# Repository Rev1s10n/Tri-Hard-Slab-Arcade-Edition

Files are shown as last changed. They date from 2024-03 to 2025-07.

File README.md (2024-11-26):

# Tri-Hard Slab: Arcade Edition
## **English | [繁體中文](README_zh-TW.md)**
A follow up from my previous [build](https://github.com/Rev1s10n/Tri-Hard-slab-v2), powered by [GP2040-CE](https://gp2040-ce.info/) firmware (v.0.7.10) with custom 16 buttons layout.<br>
This time it's made with Cherry MX switches instead of Kailh Choc switches, and CNC aluminum case with acrylic top layer for art insert.

**I would suggest not build this yourself at this momemnt as there's some design flaws, which makes it really difficult to assemble**<br>
**A new case design might come in the future**

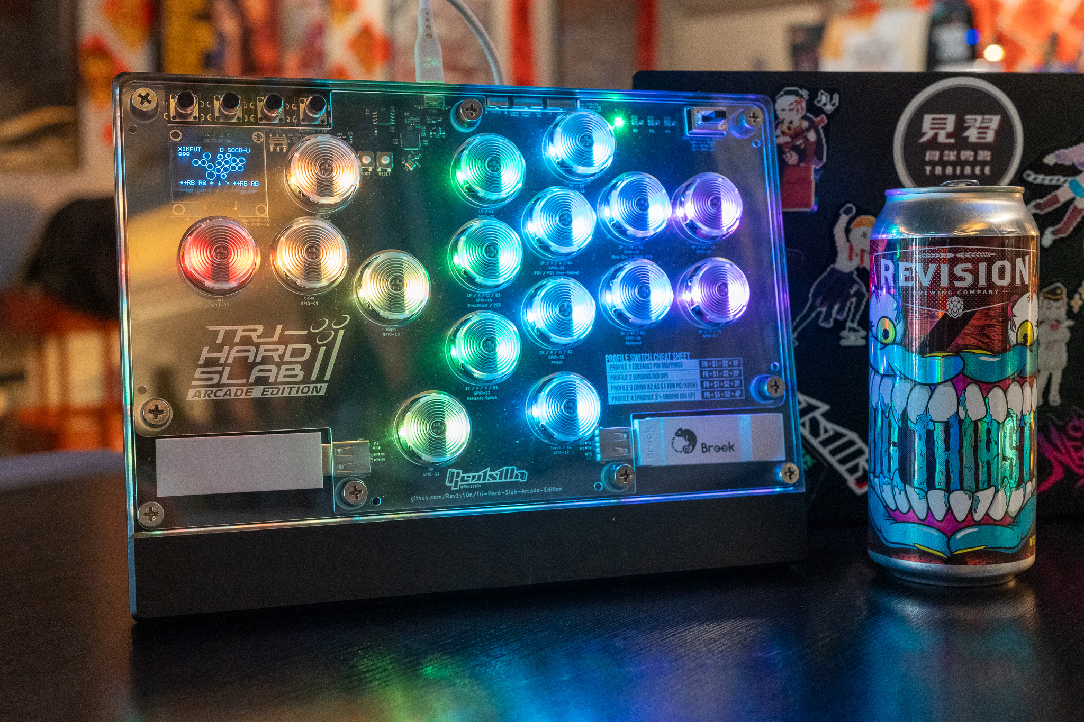
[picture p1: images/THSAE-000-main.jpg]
The beauty shot 2

## Key features and specs
- Dimensions: 270x200x24.1mm (including custom laser cut foampad)
- Weights: 1.3 kg
- Single CNC alumium case with laser cut acrylic sheet top panel and CNC polycarbonate mounting plate.
- Main key switches: any Cherry MX style switches, with hot swap sockets and Punk Workshop's key caps (25.5mm)
- Double RGB LED per key, and 4 RGB LEDs for player number indication.
- 2 USB Type-A connectors for passthrough devices, with slide switches to choose which one to activate.
- 1.3 inches OLED display.
- 3 slide switches on the top side for focus, SOCD and DP / LS / RS switch.
- Additional up button for general gaming purpose, and function key for quick profile swap.

Close up photos and feature explain:
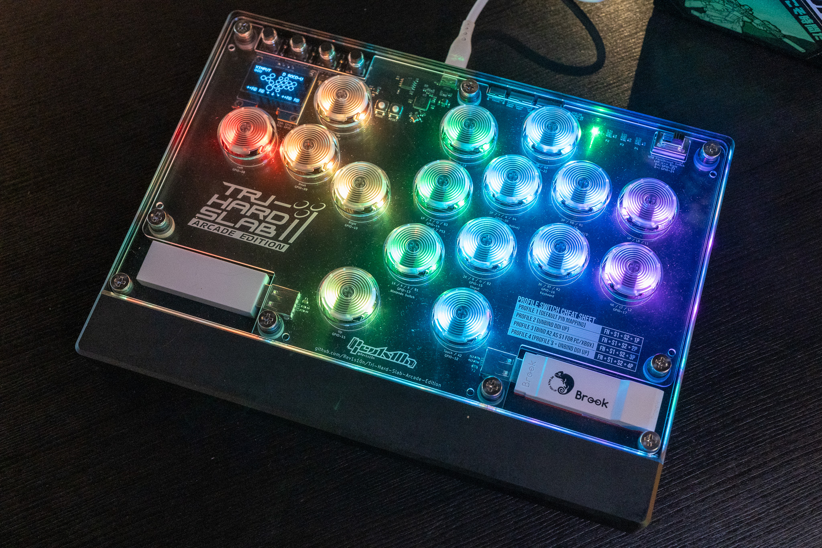
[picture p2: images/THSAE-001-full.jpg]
The core

_Fully redesigned circuit board with custom layout for my own comfort, passthrough device is now within the enclosure_
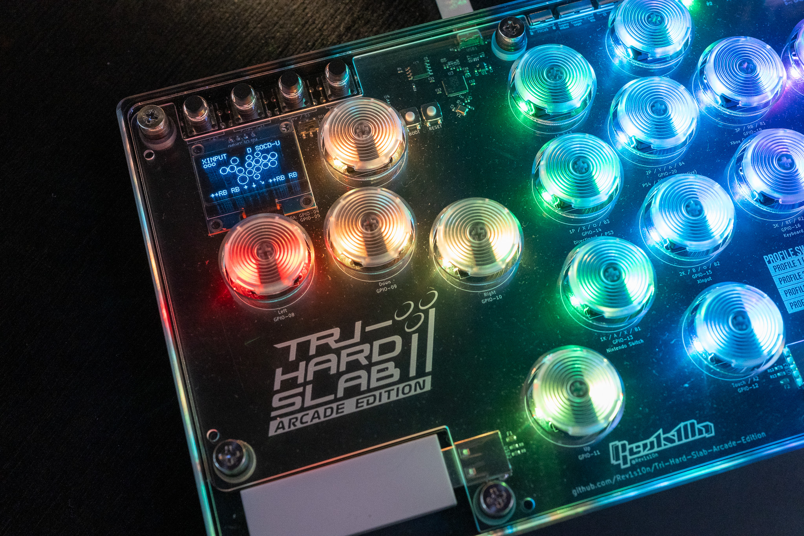
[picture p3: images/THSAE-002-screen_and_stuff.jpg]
Functions and display

_1 additional tactile switch for function key, and custom display layout_
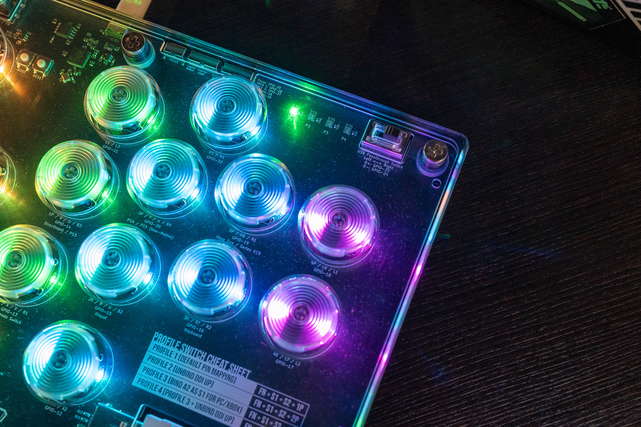
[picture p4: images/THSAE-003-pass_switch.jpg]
Passthrough switch

_Passthrough device can be selected with this slide switch_
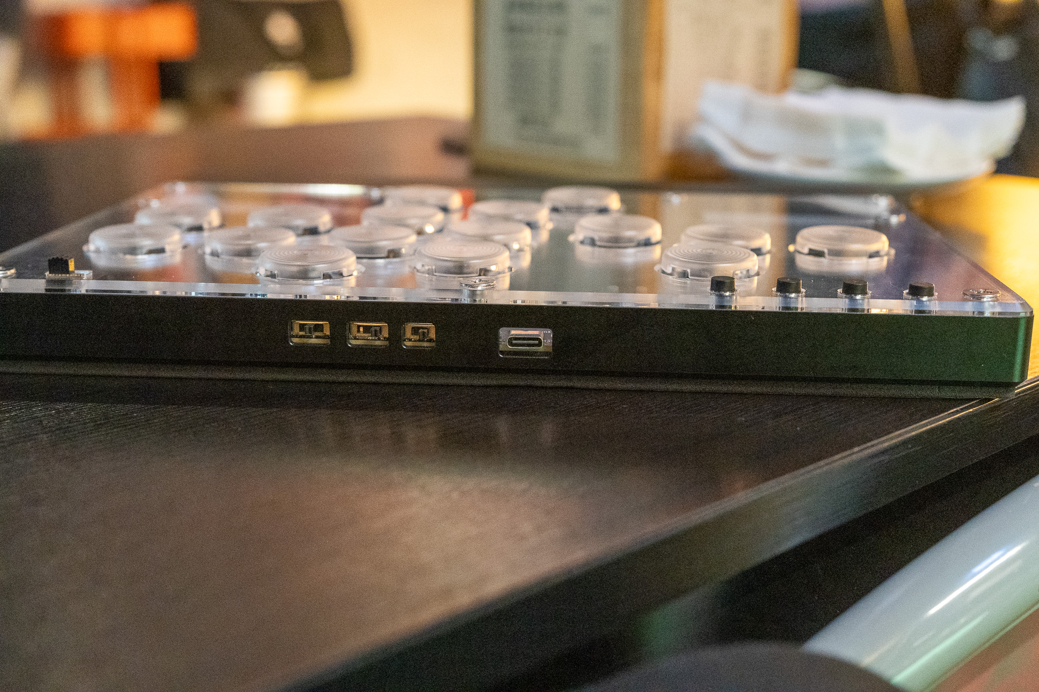
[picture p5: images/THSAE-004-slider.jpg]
Slide switches

_This time these switches is on the top side_

## Production files
Simply download all production files via Hardware files folder, and utilize services like JLCPCB (which is what I did in this case) to order the board.<br>
The board need standard PCBA for certain components. JLCPCB might told you there's some error (2 pins on 1 pad) but it's intended, and they'll make the board nevertheless.<br>
As for the case and acrylics / PC sheet, there's a step file for CNC aluminum case, 2 dxf files for laser cut acrylic, 1 dxf for CNC PC mounting plate.

## Source files
The Tri-Hard Slab AE is made with Autodesk Fusion 360 and KiCad 7.0.<br>
Everything is under Source files, include a rough Fusion 360 sketch which is the base of all laser-cut dxf files, step file and for KiCad to align things up.

## Assemble and settings
This is a bit tricky compare to original build.<br>
Here's some additional things you need to complete this build:
- Cherry MX switches, or any MX compatible switches, I use Cherry MX Black in this case.
- 16 Kailh MX hot swap socket (PG1511).
- 1.3 inches OLED display, make sure the pin order and set the slide switch accordingly.
- 9 M6 sex bolt / Chicago screws, with additional sink head screws
- Tons of hard and soft PVC washer (M6 sizes, 1mm thick) and NBR o-ring (6*2mm) for spacing.
- Custom laser cut EVA foams

There's a custom firmware with custom button layout for OLED display, and here's the GPIO pin mapping for reference:
|Keys|GPIO|
|-|-|
|Up|11|
|Down|9|
|Left|8|
|Right|10|
|B1/1K/A/Circle|13|
|B2/2K/B/Cross|15|
|B3/1P/X/Square|14|
|B4/2P/Y/Triangle|20|
|L1/4P/LB|18|
|R1/3P/RB|19|
|L2/4K/LT|17|
|R2/3K/RT|16|
|S1/Select/Back|1|
|S2/Start|3|
|L3/LS|21|
|R3/RS|22|
|A1/Home/Guide|2|
|A2/Touch|12|
|Function|0|
|Dual Direction Up|7|

Additional GPIO pin mapping and LED index for other features:
|Features|GPIO and index|
|-|-|
|RGB LED Data Pin|6|
|Player LEDs|starting from 32 to 35|
|Display SDA|4|
|Display SCL|5|
|Joystick Selection Slider Pin 1|26|
|Joystick Selection Slider Pin 2|25|
|SOCD Cleaning Mode Selection Slider Pin 1|28|
|SOCD Cleaning Mode Selection Slider Pin 2|27|
|PS Passthrough D+|23|
|PS Passthrough D-|24|
|Focus Mode Pin|29|

After load the setting file, there's 4 different profiles and there's shortcut combination to switch to any profile:
|Profile|Key combination|
|-|-|
|Profile 1 (Default pin mapping)|FN + S1 + S2 + 1P|
|Profile 2 (Unbind DDI Up)|FN + S1 + S2 + 2P|
|Profile 3 (Bind A2 as S1 for PC/Xbox)|FN + S1 + S2 + 3P|
|Profile 4 (Profile 3 + Unbind DDI Up)|FN + S1 + S2 + 4P|

## Custom artwork

You can download the PSD file and dxf drawing reference in Custom artwork template folder for top panel.<br>
Print it out and insert the artwork between 02 and 03 acrylic layers.

## Attribution
You're free to use this design as long as you credit to this page.<br>
[Licensed under CC BY 4.0](https://creativecommons.org/licenses/by/4.0/)

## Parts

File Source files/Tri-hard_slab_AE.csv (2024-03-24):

Id | Designator | Footprint | Quantity | Designation | Supplier and ref
1 | SW17,SW5,SW15,SW16,SW9,SW13,SW8,SW14,SW11,SW4,SW12,SW7,SW6,SW18,SW10 | SW_Hotswap_Kailh_Choc_V1V2 | 15 | SW_SPST
2 | SW21 | SS-13F24-G050 | 1 | ~
3 | SW3,SW2,SW1 | SW_PUSH-12mm | 3 | SW_Push
4 | SW19,SW20 | SS-12F23-G040 | 2 | ~
5 | UFB | Brook_Universal_Fighting_Board | 1 | brook_ufb
6 | R2,R1 | R_0805_2012Metric | 2 | 5.1k
7 | USB1 | USB_C_Receptacle_HRO_TYPE-C-31-M-12 | 1 | ~

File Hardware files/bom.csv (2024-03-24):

Designator | Footprint | Quantity | Value | LCSC Part #
C1, C10, C2, C8 | 0402 | 4 | 1u | C52923
C11, C12, C13, C14, C15, C16, C17, C18, C19, C20, C21, C22, C23, C24, C25, C26, C27, C28, C29, C30, C31, C32, C33, C34, C35, C36, C37, C38, C39, C40, C41, C42, C43, C44, C45, C46, C47, C48, C49, C5, C50, C51, C52, C53, C6, C7, C9 | 0402 | 47 | 100n | C1525
C3, C4 | 0402 | 2 | 30p | C161152
D1, D10, D11, D12, D13, D14, D15, D16, D17, D18, D19, D2, D20, D21, D22, D23, D24, D25, D26, D27, D28, D29, D3, D30, D31, D32, D33, D34, D35, D36, D4, D5, D6, D7, D8, D9 | SK6812-EC20 | 36 | SK6812 | C2909058
D37 | SOT-363_SC-70-6 | 1 | ~ | C15879
DS1 | 368030501246 | 1 | ~
F1, F2 | 0805 | 2 | Fuse | C116170
R1, R2 | 0402 | 2 | 5.1k | C25905
R10, R4 | 0402 | 2 | 10k | C25744
R11 | 0402 | 1 | 0 | C17168
R12, R13, R8, R9 | 0603 | 4 | 22 | C23345
R3, R5 | 0402 | 2 | 1k | C11702
R6, R7 | 0402 | 2 | 27 | C138021
SW1, SW2 | SKRAAKE010 | 2 | SW_Push | C115354
SW10 | SW_Hotswap_Kailh_MX_Plated | 1 | Up
SW11 | SW_Hotswap_Kailh_MX_Plated | 1 | 1P / X
SW12 | SW_Hotswap_Kailh_MX_Plated | 1 | 2P / Y
SW13 | SW_Hotswap_Kailh_MX_Plated | 1 | 3P / RB
SW14 | SW_Hotswap_Kailh_MX_Plated | 1 | 4P / LB
SW15 | SW_Hotswap_Kailh_MX_Plated | 1 | 1K / A
SW16 | SW_Hotswap_Kailh_MX_Plated | 1 | 2K / B
SW17 | SW_Hotswap_Kailh_MX_Plated | 1 | 3K / RT
SW18 | SW_Hotswap_Kailh_MX_Plated | 1 | 4K / LT
SW19 | SW_Hotswap_Kailh_MX_Plated | 1 | L3
SW20 | SW_Hotswap_Kailh_MX_Plated | 1 | R3
SW21 | SW_Hotswap_Kailh_MX_Plated | 1 | Touch
SW22 | SW_Hotswap_Kailh_MX_Plated | 1 | DDI_Up
SW23 | SHOU HAN SK12D07VG3 | 1 | SW_SPDT | C431547
SW24, SW25 | SHOU HAN SK13D07VG3 | 2 | SW_SP3T | C2681580
SW26 | MS-22C01-G010 | 1 | SW_DPDT | C2837066
SW27 | SS-22G88-G090 | 1 | SW_DPDT | C2848925
SW3 | TSF001A16026A | 1 | Menu | C2888706
SW4 | TSF001A16026A | 1 | Guide | C2888706
SW5 | TSF001A16026A | 1 | View | C2888706
SW6 | TSF001A16026A | 1 | FN | C2888706
SW7 | SW_Hotswap_Kailh_MX_Plated | 1 | Left
SW8 | SW_Hotswap_Kailh_MX_Plated | 1 | Down
SW9 | SW_Hotswap_Kailh_MX_Plated | 1 | Right
U1 | SOT-23-5 | 1 | TLV73333PDBV | C134139
U2 | SOIC-8_5.23x5.23mm_P1.27mm | 1 | W25Q128JVS
U3 | RP2040-QFN-56 | 1 | RP2040 | C2040
U4 | SOT-23-5 | 1 | SN74LV1T34DBVR | C100024
USB1 | HRO TYPE-C-31-M-08A | 1 | ~ | C2848616
USB2, USB3 | U-A-24DD-W-16 | 2 | USB_A | C2689981
Y1 | Crystal_SMD_3225-4Pin_3.2x2.5mm | 1 | Crystal_GND24 | C9002

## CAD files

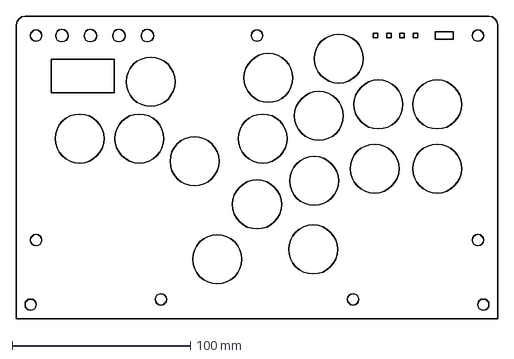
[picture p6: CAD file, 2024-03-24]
Custom artwork template/art_panel.dxf
270.0 x 170.0 mm

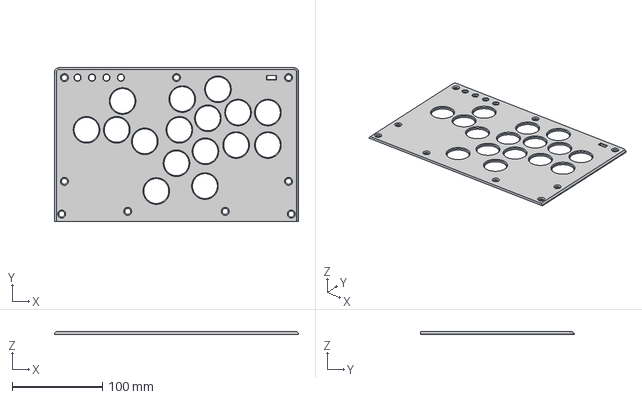
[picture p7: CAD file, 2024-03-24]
Enclosure/03_Acrylic_top_3mm_for_ref.step
270.0 x 170.0 x 3.00 mm

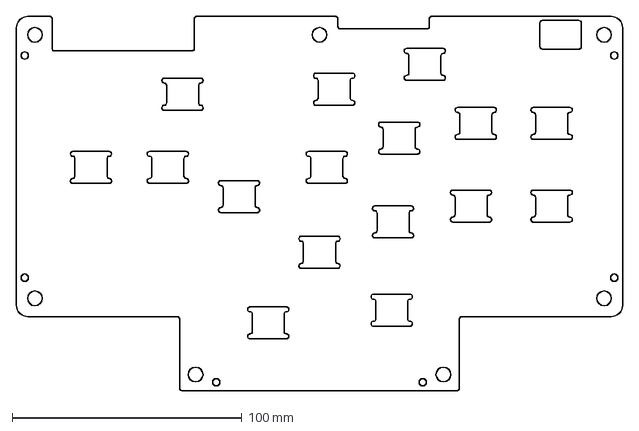
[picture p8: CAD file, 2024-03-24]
Enclosure/01_PC_mounting_plate_1.5mm_cnc_fixed.dxf
264.0 x 163.0 mm

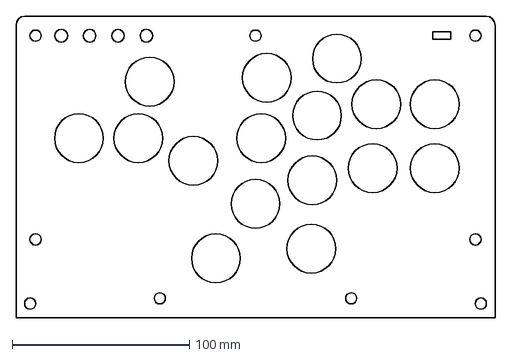
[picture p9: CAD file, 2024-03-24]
Enclosure/03_Acrylic_top_3mm.dxf
270.0 x 170.0 mm

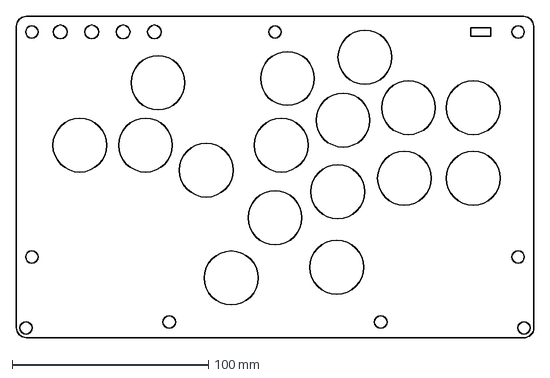
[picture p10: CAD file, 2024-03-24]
Enclosure/02_Acrylic_2mm.dxf
264.0 x 164.0 mm

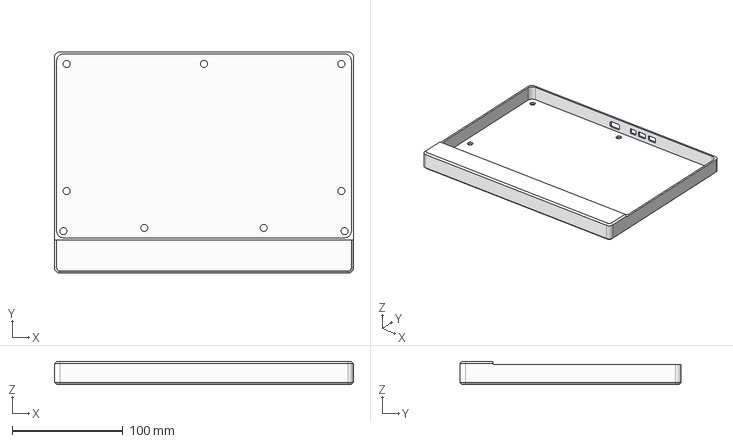
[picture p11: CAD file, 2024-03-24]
Enclosure/case.step
270.0 x 200.0 x 21.1 mm

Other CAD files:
Source files/Panel_v3_box.f3d

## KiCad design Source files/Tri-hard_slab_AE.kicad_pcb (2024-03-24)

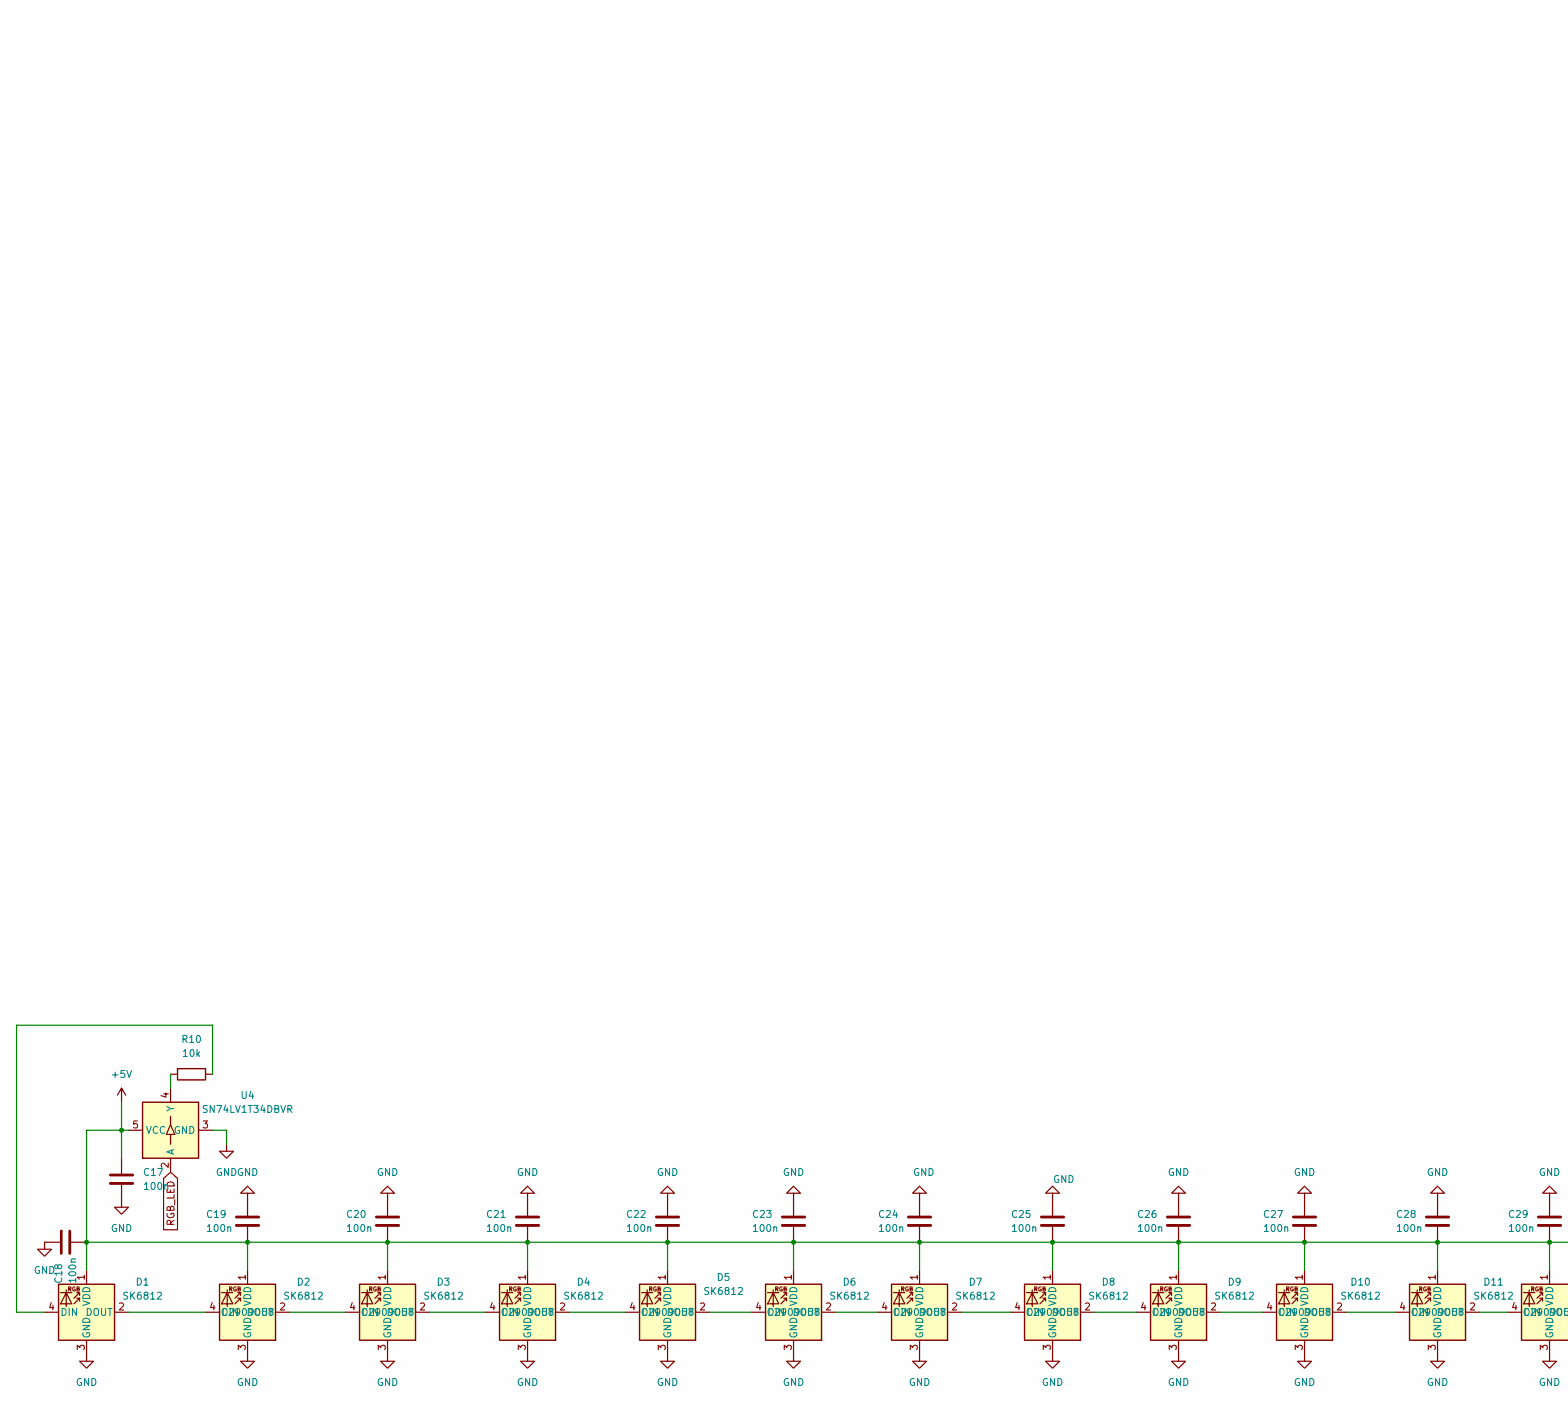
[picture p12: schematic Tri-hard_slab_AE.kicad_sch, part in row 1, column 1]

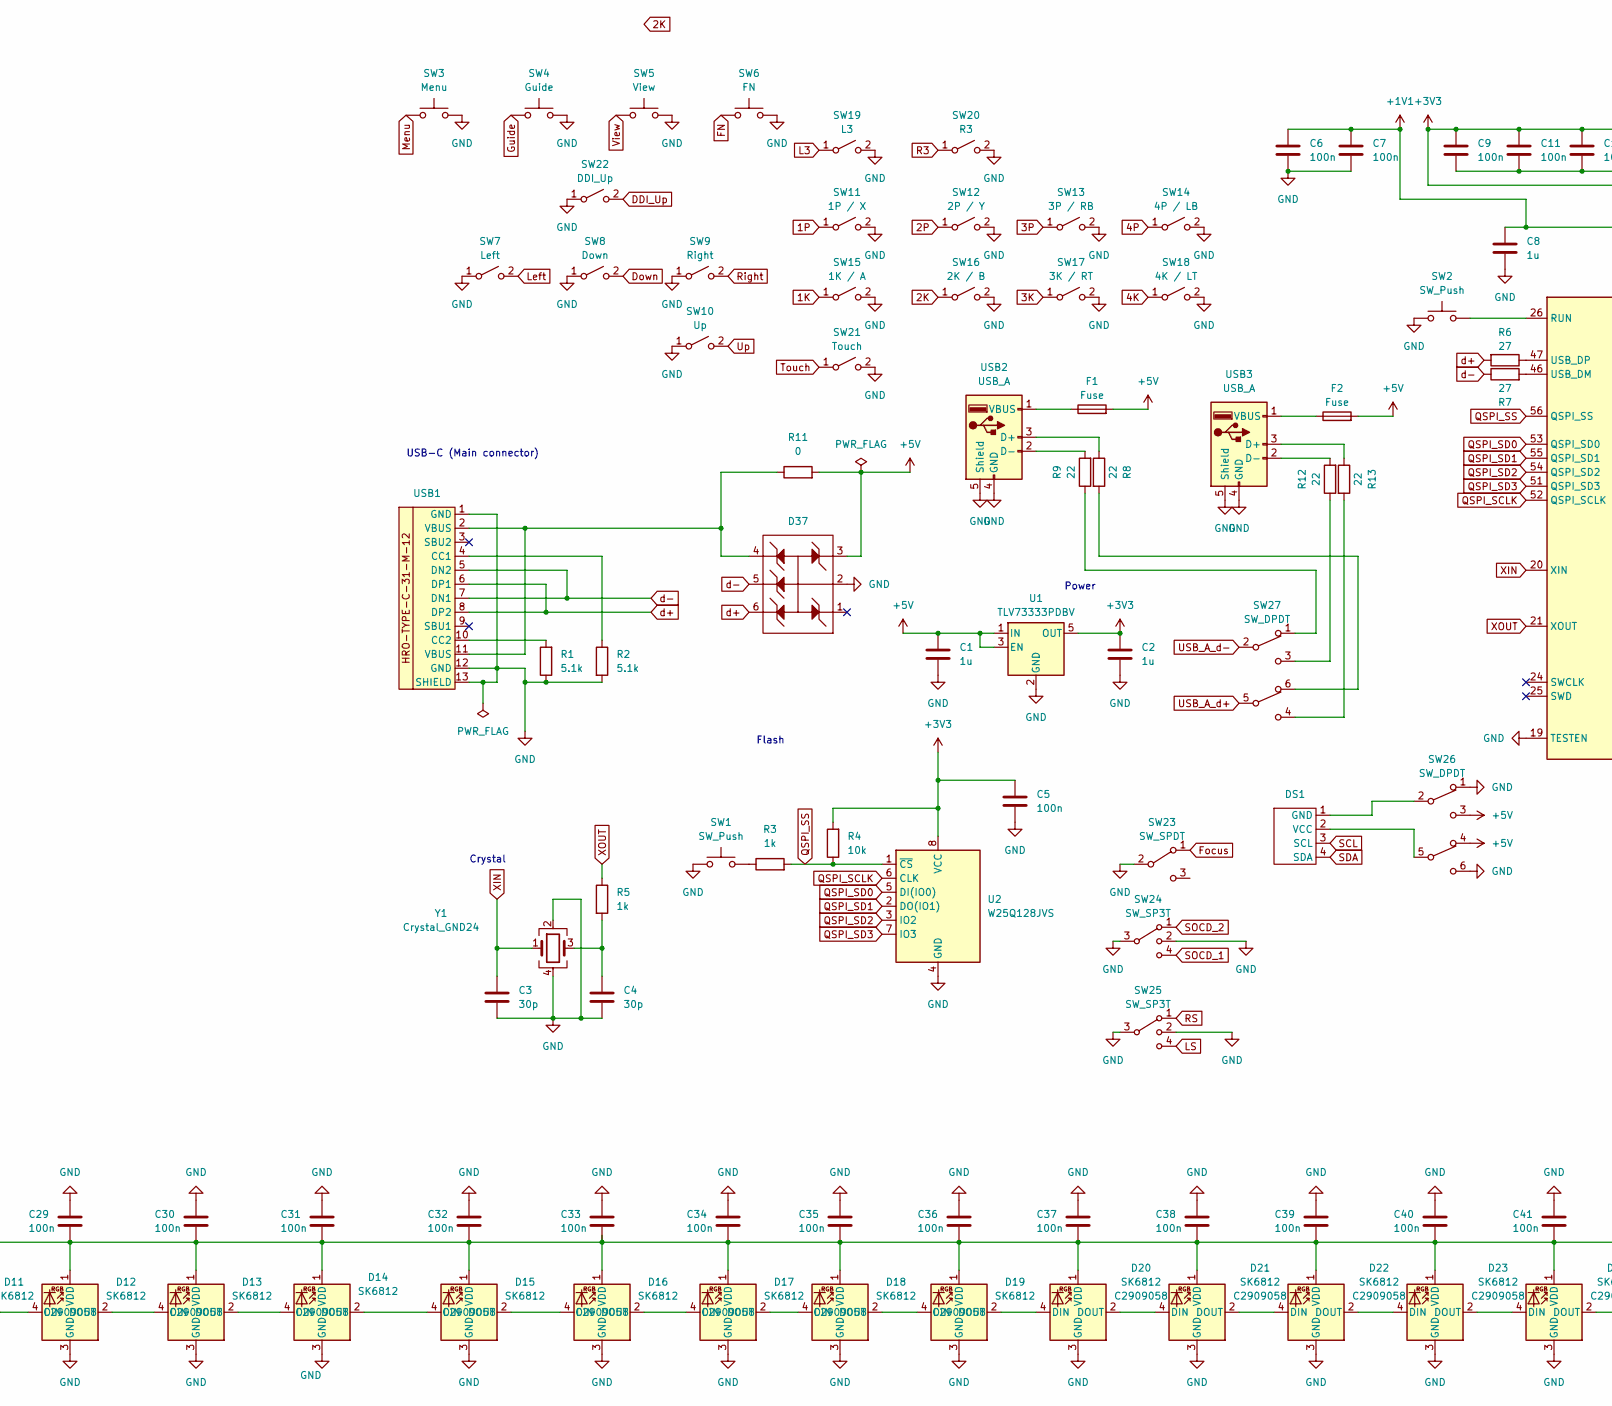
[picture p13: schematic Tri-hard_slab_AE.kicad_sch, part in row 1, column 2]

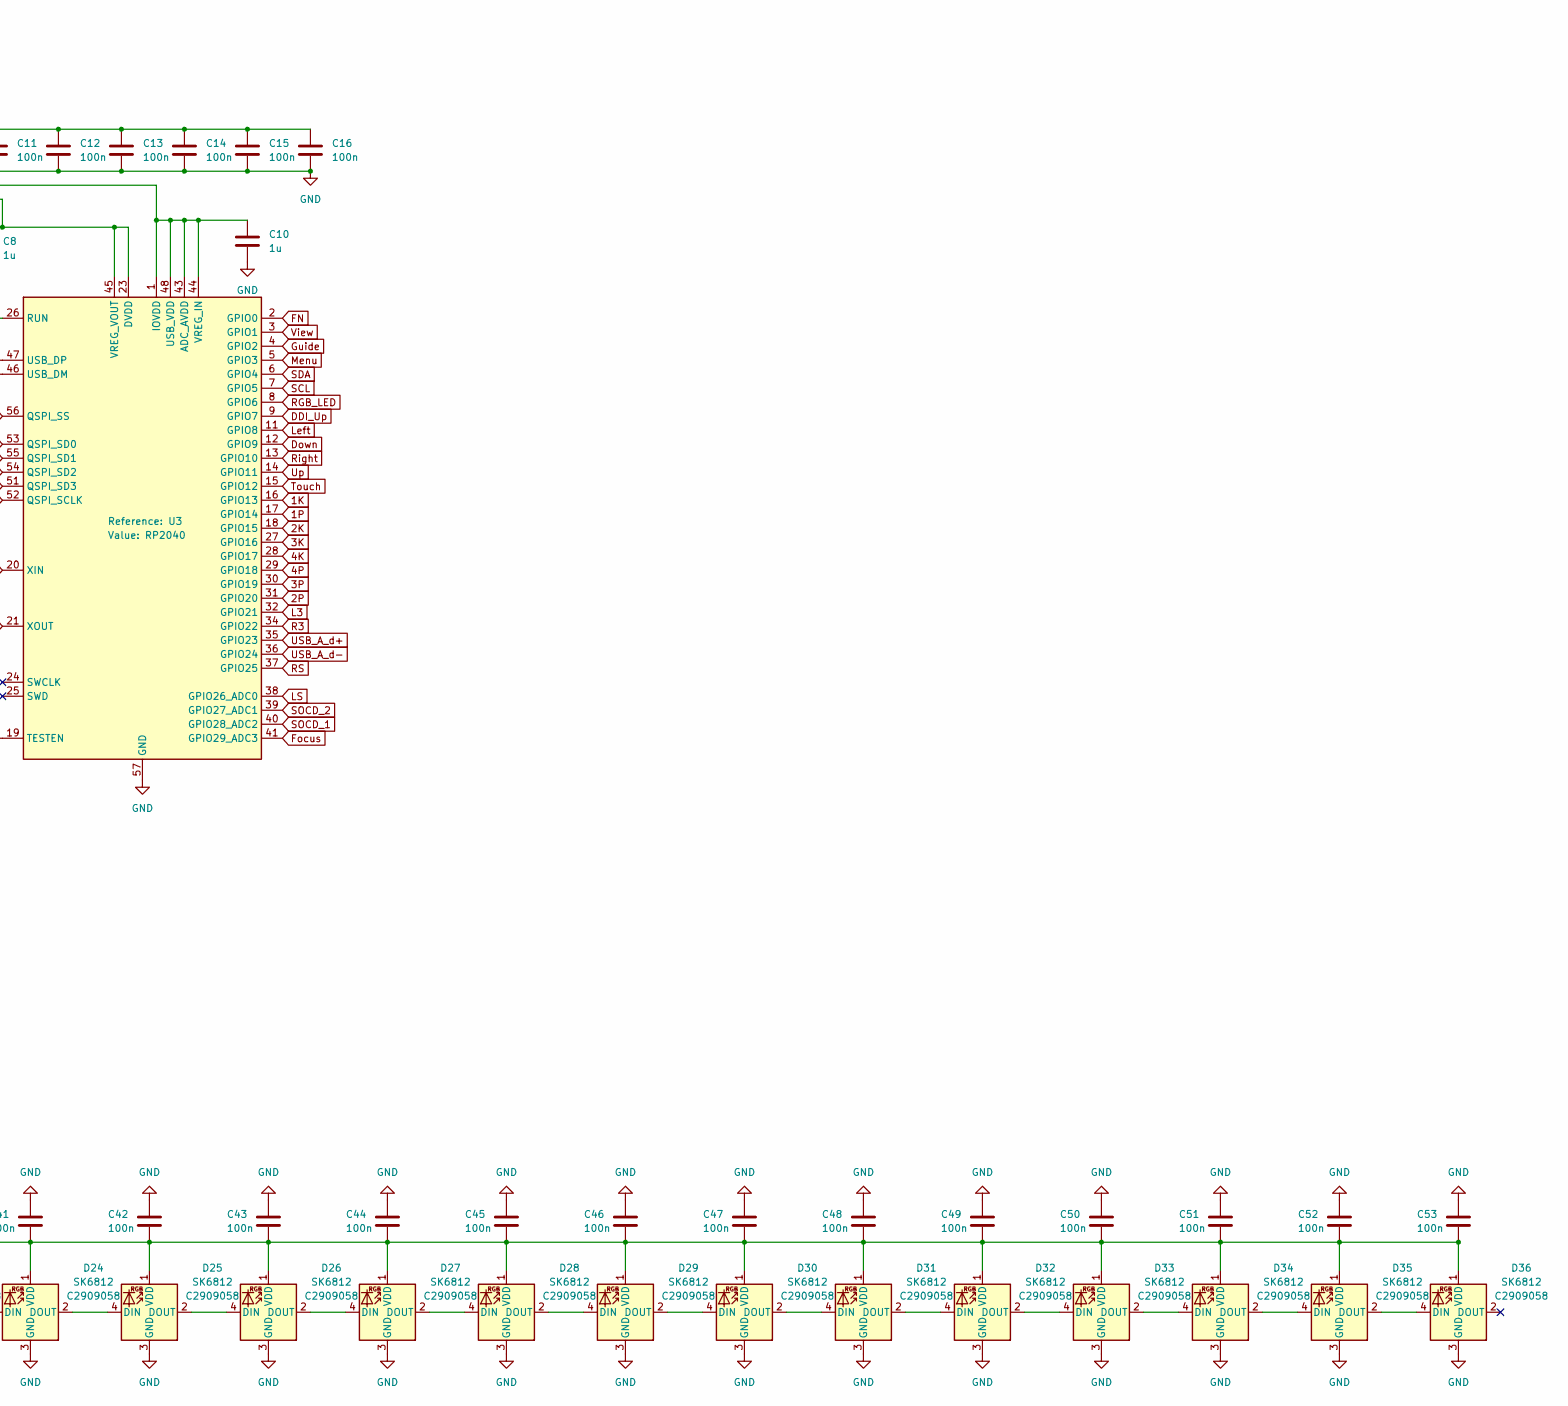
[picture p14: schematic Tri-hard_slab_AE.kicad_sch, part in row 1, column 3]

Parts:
C1, C2, C8, C10: 1u; C_0402_1005Metric; LCSC C52923
C3, C4: 30p; C_0402_1005Metric; LCSC C161152
C5, C6, C7, C9, C11, C12, C13, C14, C15, C16, C17, C18, C19, C20, C21, C22, C23, C24, C25, C26, C27, C28, C29, C30, C31, C32, C33, C34, C35, C36, C37, C38, C39, C40, C41, C42, C43, C44, C45, C46, C47, C48, C49, C50, C51, C52, C53: 100n; C_0402_1005Metric; LCSC C1525
D1, D2, D3, D4, D5, D6, D7, D8, D9, D10, D11, D12, D13, D14, D15, D16, D17, D18, D19, D20, D21, D22, D23, D24, D25, D26, D27, D28, D29, D30, D31, D32, D33, D34, D35, D36: SK6812; SK6812-EC20; LCSC C2909058
D37: SOT-363_SC-70-6; LCSC C15879
DS1: 368030501246
F1, F2: Fuse; Fuse_0805_2012Metric; LCSC C116170
R1, R2: 5.1k; R_0402_1005Metric; LCSC C25905
R3, R5: 1k; R_0402_1005Metric; LCSC C11702
R4, R10: 10k; R_0402_1005Metric; LCSC C25744
R6, R7: 27; R_0402_1005Metric; LCSC C138021
R8, R9, R12, R13: 22; R_0603_1608Metric; LCSC C23345
R11: 0; R_0402_1005Metric; LCSC C17168
SW1, SW2: SW_Push; SKRAAKE010; LCSC C115354
SW3: Menu; TSF001A16026A; LCSC C2888706
SW4: Guide; TSF001A16026A; LCSC C2888706
SW5: View; TSF001A16026A; LCSC C2888706
SW6: FN; TSF001A16026A; LCSC C2888706
SW7: Left; SW_Hotswap_Kailh_MX_Plated
SW8: Down; SW_Hotswap_Kailh_MX_Plated
SW9: Right; SW_Hotswap_Kailh_MX_Plated
SW10: Up; SW_Hotswap_Kailh_MX_Plated
SW11: 1P / X; SW_Hotswap_Kailh_MX_Plated
SW12: 2P / Y; SW_Hotswap_Kailh_MX_Plated
SW13: 3P / RB; SW_Hotswap_Kailh_MX_Plated
SW14: 4P / LB; SW_Hotswap_Kailh_MX_Plated
SW15: 1K / A; SW_Hotswap_Kailh_MX_Plated
SW16: 2K / B; SW_Hotswap_Kailh_MX_Plated
SW17: 3K / RT; SW_Hotswap_Kailh_MX_Plated
SW18: 4K / LT; SW_Hotswap_Kailh_MX_Plated
SW19: L3; SW_Hotswap_Kailh_MX_Plated
SW20: R3; SW_Hotswap_Kailh_MX_Plated
SW21: Touch; SW_Hotswap_Kailh_MX_Plated
SW22: DDI_Up; SW_Hotswap_Kailh_MX_Plated
SW23: SW_SPDT; SHOU HAN SK12D07VG3; LCSC C431547
SW24, SW25: SW_SP3T; SHOU HAN SK13D07VG3; LCSC C2681580
SW26: SW_DPDT; MS-22C01-G010; LCSC C2837066
SW27: SW_DPDT; SS-22G88-G090; LCSC C2848925
U1: TLV73333PDBV; SOT-23-5; LCSC C134139
U2: W25Q128JVS; SOIC-8_5.23x5.23mm_P1.27mm
U3: RP2040; RP2040-QFN-56; LCSC C2040
U4: SN74LV1T34DBVR; SOT-23-5; LCSC C100024
USB1: HRO TYPE-C-31-M-08A; LCSC C2848616
USB2, USB3: USB_A; U-A-24DD-W-16; LCSC C2689981
Y1: Crystal_GND24; Crystal_SMD_3225-4Pin_3.2x2.5mm; LCSC C9002

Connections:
1K: SW15.1 (A), U3.16 (GPIO13)
1P: SW11.1 (A), U3.17 (GPIO14)
2K: SW16.1 (A), U3.18 (GPIO15)
2P: SW12.1 (A), U3.31 (GPIO20)
3K: SW17.1 (A), U3.27 (GPIO16)
3P: SW13.1 (A), U3.30 (GPIO19)
4K: SW18.1 (A), U3.28 (GPIO17)
4P: SW14.1 (A), U3.29 (GPIO18)
+1V1: C6.1, C7.1, C8.1, U3.23 (DVDD), U3.45 (VREG_VOUT), U3.50 (DVDD)
+3V3: C2.1, C5.1, C9.1, C10.1, C11.1, C12.1, C13.1, C14.1, C15.1, C16.1, R4.2, U1.5 (OUT), U2.8 (VCC), U3.1 (IOVDD), U3.10 (IOVDD), U3.22 (IOVDD), U3.33 (IOVDD), U3.42 (IOVDD), U3.43 (ADC_AVDD), U3.44 (VREG_IN), U3.48 (USB_VDD), U3.49 (IOVDD)
+5V: C1.1, C17.1, C18.1, C19.1, C20.1, C21.1, C22.1, C23.1, C24.1, C25.1, C26.1, C27.1, C28.1, C29.1, C30.1, C31.1, C32.1, C33.1, C34.1, C35.1, C36.1, C37.1, C38.1, C39.1, C40.1, C41.1, C42.1, C43.1, C44.1, C45.1, C46.1, C47.1, C48.1, C49.1, C50.1, C51.1, C52.1, C53.1, D1.1 (VDD), D2.1 (VDD), D3.1 (VDD), D4.1 (VDD), D5.1 (VDD), D6.1 (VDD), D7.1 (VDD), D8.1 (VDD), D9.1 (VDD), D10.1 (VDD), D11.1 (VDD), D12.1 (VDD), D13.1 (VDD), D14.1 (VDD), D15.1 (VDD), D16.1 (VDD), D17.1 (VDD), D18.1 (VDD), D19.1 (VDD), D20.1 (VDD), D21.1 (VDD), D22.1 (VDD), D23.1 (VDD), D24.1 (VDD), D25.1 (VDD), D26.1 (VDD), D27.1 (VDD), D28.1 (VDD), D29.1 (VDD), D30.1 (VDD), D31.1 (VDD), D32.1 (VDD), D33.1 (VDD), D34.1 (VDD), D35.1 (VDD), D36.1 (VDD), D37.3, F1.2, F2.2, R11.2, SW26.3 (C), SW26.4 (A), U1.1 (IN), U1.3 (EN), U4.5 (VCC)
DDI_Up: SW22.2 (B), U3.9 (GPIO7)
Down: SW8.2 (B), U3.12 (GPIO9)
FN: SW6.1, U3.2 (GPIO0)
Focus: SW23.1 (A), U3.41 (GPIO29_ADC3)
GND: C1.2, C2.2, C3.2, C4.2, C5.2, C6.2, C7.2, C8.2, C9.2, C10.2, C11.2, C12.2, C13.2, C14.2, C15.2, C16.2, C17.2, C18.2, C19.2, C20.2, C21.2, C22.2, C23.2, C24.2, C25.2, C26.2, C27.2, C28.2, C29.2, C30.2, C31.2, C32.2, C33.2, C34.2, C35.2, C36.2, C37.2, C38.2, C39.2, C40.2, C41.2, C42.2, C43.2, C44.2, C45.2, C46.2, C47.2, C48.2, C49.2, C50.2, C51.2, C52.2, C53.2, D1.3 (GND), D2.3 (GND), D3.3 (GND), D4.3 (GND), D5.3 (GND), D6.3 (GND), D7.3 (GND), D8.3 (GND), D9.3 (GND), D10.3 (GND), D11.3 (GND), D12.3 (GND), D13.3 (GND), D14.3 (GND), D15.3 (GND), D16.3 (GND), D17.3 (GND), D18.3 (GND), D19.3 (GND), D20.3 (GND), D21.3 (GND), D22.3 (GND), D23.3 (GND), D24.3 (GND), D25.3 (GND), D26.3 (GND), D27.3 (GND), D28.3 (GND), D29.3 (GND), D30.3 (GND), D31.3 (GND), D32.3 (GND), D33.3 (GND), D34.3 (GND), D35.3 (GND), D36.3 (GND), D37.2, R1.1, R2.2, SW1.1, SW2.1, SW3.2, SW4.2, SW5.2, SW6.2, SW7.1 (A), SW8.1 (A), SW9.1 (A), SW10.1 (A), SW11.2 (B), SW12.2 (B), SW13.2 (B), SW14.2 (B), SW15.2 (B), SW16.2 (B), SW17.2 (B), SW18.2 (B), SW19.2 (B), SW20.2 (B), SW21.2 (B), SW22.1 (A), SW23.2 (B), SW23.GND, SW24.2, SW24.3, SW24.GND, SW25.2, SW25.3, SW25.GND, SW26.1 (A), SW26.6 (C), U1.2 (GND), U2.4 (GND), U3.19 (TESTEN), U3.57 (GND), U4.3 (GND), USB1.1 (GND), USB1.12 (GND), USB1.13 (SHIELD), USB2.4 (GND), USB2.5 (Shield), USB3.4 (GND), USB3.5 (Shield), Y1.2, Y1.4
Guide: SW4.1, U3.4 (GPIO2)
L3: SW19.1 (A), U3.32 (GPIO21)
LS: SW25.4, U3.38 (GPIO26_ADC0)
Left: SW7.2 (B), U3.11 (GPIO8)
Menu: SW3.1, U3.5 (GPIO3)
unnamed: C4.1, R5.2, Y1.3
unnamed: D1.4 (DIN), R10.1
unnamed: D1.2 (DOUT), D2.4 (DIN)
unnamed: D2.2 (DOUT), D3.4 (DIN)
unnamed: D3.2 (DOUT), D4.4 (DIN)
unnamed: D4.2 (DOUT), D5.4 (DIN)
unnamed: D5.2 (DOUT), D6.4 (DIN)
unnamed: D6.2 (DOUT), D7.4 (DIN)
unnamed: D7.2 (DOUT), D8.4 (DIN)
unnamed: D8.2 (DOUT), D9.4 (DIN)
unnamed: D9.2 (DOUT), D10.4 (DIN)
unnamed: D10.2 (DOUT), D11.4 (DIN)
unnamed: D11.2 (DOUT), D12.4 (DIN)
unnamed: D12.2 (DOUT), D13.4 (DIN)
unnamed: D13.2 (DOUT), D14.4 (DIN)
unnamed: D14.2 (DOUT), D15.4 (DIN)
unnamed: D15.2 (DOUT), D16.4 (DIN)
unnamed: D16.2 (DOUT), D17.4 (DIN)
unnamed: D17.2 (DOUT), D18.4 (DIN)
unnamed: D18.2 (DOUT), D19.4 (DIN)
unnamed: D19.2 (DOUT), D20.4 (DIN)
unnamed: D20.2 (DOUT), D21.4 (DIN)
unnamed: D21.2 (DOUT), D22.4 (DIN)
unnamed: D22.2 (DOUT), D23.4 (DIN)
unnamed: D23.2 (DOUT), D24.4 (DIN)
unnamed: D24.2 (DOUT), D25.4 (DIN)
unnamed: D25.2 (DOUT), D26.4 (DIN)
unnamed: D26.2 (DOUT), D27.4 (DIN)
unnamed: D27.2 (DOUT), D28.4 (DIN)
unnamed: D28.2 (DOUT), D29.4 (DIN)
unnamed: D29.2 (DOUT), D30.4 (DIN)
unnamed: D30.2 (DOUT), D31.4 (DIN)
unnamed: D31.2 (DOUT), D32.4 (DIN)
unnamed: D32.2 (DOUT), D33.4 (DIN)
unnamed: D33.2 (DOUT), D34.4 (DIN)
unnamed: D34.2 (DOUT), D35.4 (DIN)
unnamed: D35.2 (DOUT), D36.4 (DIN)
unnamed: D37.4, R11.1, USB1.2 (VBUS), USB1.11 (VBUS)
unnamed: DS1.1 (GND), SW26.2 (B)
unnamed: DS1.2 (VCC), SW26.5 (B)
unnamed: R3.1, SW1.2
unnamed: R8.2, SW27.6 (A)
unnamed: R9.1, SW27.1 (A)
unnamed: R12.1, SW27.3 (C)
unnamed: R13.2, SW27.4 (C)
unnamed: SW2.2, U3.26 (RUN)
unnamed: R7.2, U3.46 (USB_DM)
unnamed: R6.1, U3.47 (USB_DP)
unnamed: R10.2, U4.4 (Y)
unnamed: R2.1, USB1.4 (CC1)
unnamed: R1.2, USB1.10 (CC2)
unnamed: R8.1, USB2.3 (D+)
unnamed: R9.2, USB2.2 (D-)
unnamed: F1.1, USB2.1 (VBUS)
unnamed: R13.1, USB3.3 (D+)
unnamed: R12.2, USB3.2 (D-)
unnamed: F2.1, USB3.1 (VBUS)
QSPI_SCLK: U2.6 (CLK), U3.52 (QSPI_SCLK)
QSPI_SD0: U2.5 (DI(IO0)), U3.53 (QSPI_SD0)
QSPI_SD1: U2.2 (DO(IO1)), U3.55 (QSPI_SD1)
QSPI_SD2: U2.3 (IO2), U3.54 (QSPI_SD2)
QSPI_SD3: U2.7 (IO3), U3.51 (QSPI_SD3)
QSPI_SS: R3.2, R4.1, U2.1 (~CS), U3.56 (QSPI_SS)
R3: SW20.1 (A), U3.34 (GPIO22)
RGB_LED: U3.8 (GPIO6), U4.2 (A)
RS: SW25.1, U3.37 (GPIO25)
Right: SW9.2 (B), U3.13 (GPIO10)
SCL: DS1.3 (SCL), U3.7 (GPIO5)
SDA: DS1.4 (SDA), U3.6 (GPIO4)
SOCD_1: SW24.4, U3.40 (GPIO28_ADC2)
SOCD_2: SW24.1, U3.39 (GPIO27_ADC1)
Touch: SW21.1 (A), U3.15 (GPIO12)
USB_A_d+: SW27.5 (B), U3.35 (GPIO23)
USB_A_d-: SW27.2 (B), U3.36 (GPIO24)
Up: SW10.2 (B), U3.14 (GPIO11)
View: SW5.1, U3.3 (GPIO1)
XIN: C3.1, U3.20 (XIN), Y1.1
XOUT: R5.1, U3.21 (XOUT)
d+: D37.6, R6.2, USB1.6 (DP1), USB1.8 (DP2)
d-: D37.5, R7.1, USB1.5 (DN2), USB1.7 (DN1)

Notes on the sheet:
Crystal
USB-C (Main connector)
Flash
Power

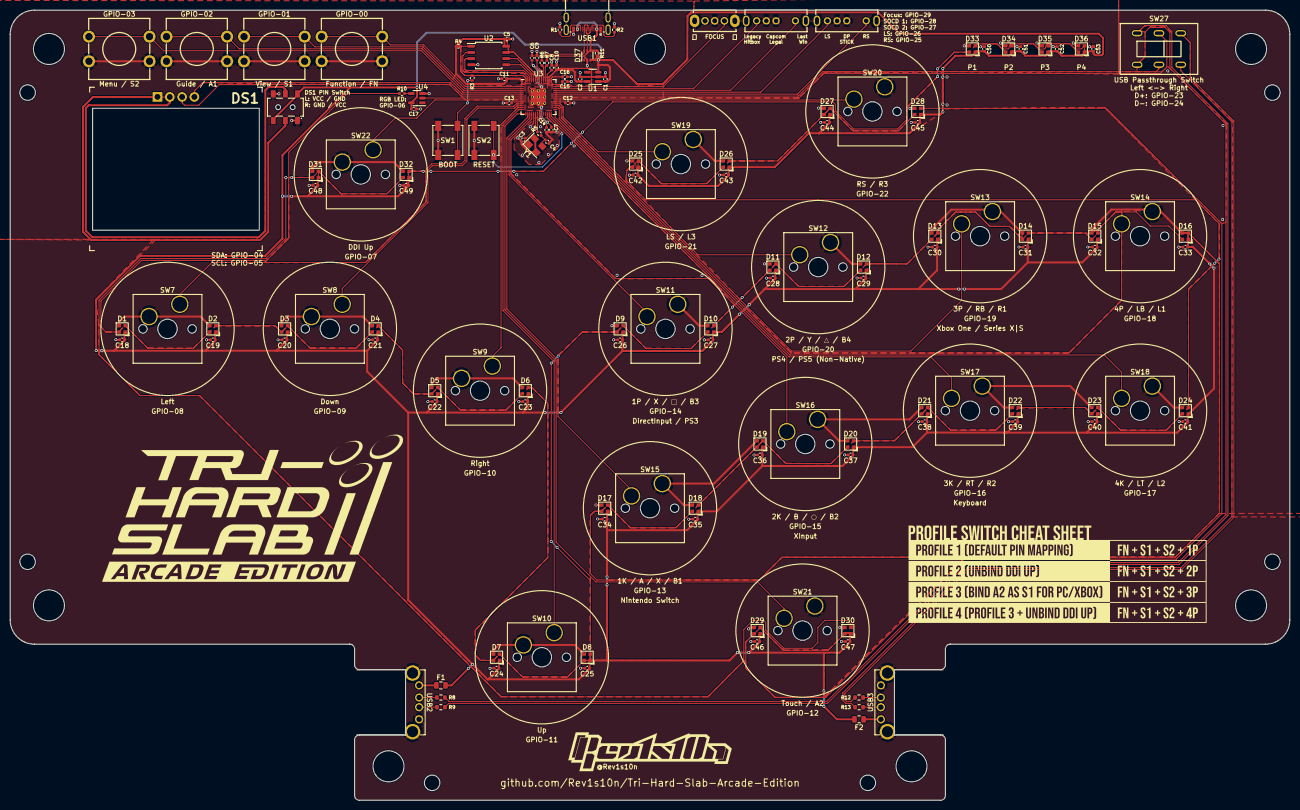
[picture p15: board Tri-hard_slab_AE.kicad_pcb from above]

Board: 2 copper layers, 264.0 x 163.0 mm, 141 parts (0 on the bottom side), 101 nets.

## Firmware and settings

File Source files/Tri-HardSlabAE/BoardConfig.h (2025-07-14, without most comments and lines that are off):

#define PICO_BOARD_CONFIG_H_
#include "enums.pb.h"
#include "class/hid/hid.h"
#define BOARD_CONFIG_LABEL "Tri-Hard_Slab-AE"
#define GPIO_PIN_11 GpioAction::BUTTON_PRESS_UP     // UP     | UP     | UP      | UP       | UP     | UP     |
#define GPIO_PIN_09 GpioAction::BUTTON_PRESS_DOWN   // DOWN   | DOWN   | DOWN    | DOWN     | DOWN   | DOWN   |
#define GPIO_PIN_10 GpioAction::BUTTON_PRESS_RIGHT  // RIGHT  | RIGHT  | RIGHT   | RIGHT    | RIGHT  | RIGHT  |
#define GPIO_PIN_08 GpioAction::BUTTON_PRESS_LEFT   // LEFT   | LEFT   | LEFT    | LEFT     | LEFT   | LEFT   |
#define GPIO_PIN_13 GpioAction::BUTTON_PRESS_B1     // B1     | A      | B       | Cross    | 2      | K1     |
#define GPIO_PIN_15 GpioAction::BUTTON_PRESS_B2     // B2     | B      | A       | Circle   | 3      | K2     |
#define GPIO_PIN_16 GpioAction::BUTTON_PRESS_R2     // R2     | RT     | ZR      | R2       | 8      | K3     |
#define GPIO_PIN_17 GpioAction::BUTTON_PRESS_L2     // L2     | LT     | ZL      | L2       | 7      | K4     |
#define GPIO_PIN_14 GpioAction::BUTTON_PRESS_B3     // B3     | X      | Y       | Square   | 1      | P1     |
#define GPIO_PIN_20 GpioAction::BUTTON_PRESS_B4     // B4     | Y      | X       | Triangle | 4      | P2     |
#define GPIO_PIN_19 GpioAction::BUTTON_PRESS_R1     // R1     | RB     | R       | R1       | 6      | P3     |
#define GPIO_PIN_18 GpioAction::BUTTON_PRESS_L1     // L1     | LB     | L       | L1       | 5      | P4     |
#define GPIO_PIN_01 GpioAction::BUTTON_PRESS_S1     // S1     | Back   | Minus   | Select   | 9      | Coin   |
#define GPIO_PIN_03 GpioAction::BUTTON_PRESS_S2     // S2     | Start  | Plus    | Start    | 10     | Start  |
#define GPIO_PIN_21 GpioAction::BUTTON_PRESS_L3     // L3     | LS     | LS      | L3       | 11     | LS     |
#define GPIO_PIN_22 GpioAction::BUTTON_PRESS_R3     // R3     | RS     | RS      | R3       | 12     | RS     |
#define GPIO_PIN_02 GpioAction::BUTTON_PRESS_A1     // A1     | Guide  | Home    | PS       | 13     | ~      |
#define GPIO_PIN_12 GpioAction::BUTTON_PRESS_A2     // A2     | ~      | Capture | ~        | 14     | ~      |
#define GPIO_PIN_07 GpioAction::BUTTON_PRESS_DDI_UP // DDI_UP | UP     | UP      | UP       | UP     | UP     |
#define GPIO_PIN_00 GpioAction::BUTTON_PRESS_FN     // Hotkey Function                                        |
#define KEY_DPAD_UP     HID_KEY_ARROW_UP      // UP     | UP     | UP      | UP       | UP     | UP     |
#define KEY_DPAD_DOWN   HID_KEY_ARROW_DOWN    // DOWN   | DOWN   | DOWN    | DOWN     | DOWN   | DOWN   |
#define KEY_DPAD_RIGHT  HID_KEY_ARROW_RIGHT   // RIGHT  | RIGHT  | RIGHT   | RIGHT    | RIGHT  | RIGHT  |
#define KEY_DPAD_LEFT   HID_KEY_ARROW_LEFT    // LEFT   | LEFT   | LEFT    | LEFT     | LEFT   | LEFT   |
#define KEY_BUTTON_B1   HID_KEY_SHIFT_LEFT    // B1     | A      | B       | Cross    | 2      | K1     |
#define KEY_BUTTON_B2   HID_KEY_Z             // B2     | B      | A       | Circle   | 3      | K2     |
#define KEY_BUTTON_R2   HID_KEY_X             // R2     | RT     | ZR      | R2       | 8      | K3     |
#define KEY_BUTTON_L2   HID_KEY_V             // L2     | LT     | ZL      | L2       | 7      | K4     |
#define KEY_BUTTON_B3   HID_KEY_CONTROL_LEFT  // B3     | X      | Y       | Square   | 1      | P1     |
#define KEY_BUTTON_B4   HID_KEY_ALT_LEFT      // B4     | Y      | X       | Triangle | 4      | P2     |
#define KEY_BUTTON_R1   HID_KEY_SPACE         // R1     | RB     | R       | R1       | 6      | P3     |
#define KEY_BUTTON_L1   HID_KEY_C             // L1     | LB     | L       | L1       | 5      | P4     |
#define KEY_BUTTON_S1   HID_KEY_5             // S1     | Back   | Minus   | Select   | 9      | Coin   |
#define KEY_BUTTON_S2   HID_KEY_1             // S2     | Start  | Plus    | Start    | 10     | Start  |
#define KEY_BUTTON_L3   HID_KEY_EQUAL         // L3     | LS     | LS      | L3       | 11     | LS     |
#define KEY_BUTTON_R3   HID_KEY_MINUS         // R3     | RS     | RS      | R3       | 12     | RS     |
#define KEY_BUTTON_A1   HID_KEY_9             // A1     | Guide  | Home    | PS       | 13     | ~      |
#define KEY_BUTTON_A2   HID_KEY_F2            // A2     | ~      | Capture | ~        | 14     | ~      |
#define KEY_BUTTON_FN   -1                    // Hotkey Function                                        |
#define GPIO_PIN_26 GpioAction::SUSTAIN_DP_MODE_LS
#define GPIO_PIN_25 GpioAction::SUSTAIN_DP_MODE_RS
#define SLIDER_SOCD_ENABLED 1
#define GPIO_PIN_28 GpioAction::SUSTAIN_SOCD_MODE_UP_PRIO
#define GPIO_PIN_27 GpioAction::SUSTAIN_SOCD_MODE_SECOND_WIN
#define SLIDER_SOCD_SLOT_DEFAULT SOCD_MODE_NEUTRAL
#define DEFAULT_INPUT_MODE_R1 INPUT_MODE_XBONE
#define DEFAULT_INPUT_MODE_B4 INPUT_MODE_PS5
#define DEFAULT_PS5AUTHENTICATION_TYPE INPUT_MODE_AUTH_TYPE_USB
#define BOARD_LEDS_PIN 6
#define LED_BRIGHTNESS_MAXIMUM 255
#define LEDS_PER_PIXEL 2
#define LEDS_DPAD_LEFT   0
#define LEDS_DPAD_DOWN   1
#define LEDS_DPAD_RIGHT  2
#define LEDS_DPAD_UP     3
#define LEDS_BUTTON_B3   4
#define LEDS_BUTTON_B4   5
#define LEDS_BUTTON_R1   6
#define LEDS_BUTTON_L1   7
#define LEDS_BUTTON_B1   8
#define LEDS_BUTTON_B2   9
#define LEDS_BUTTON_R2   10
#define LEDS_BUTTON_L2   11
#define LEDS_BUTTON_L3   12
#define LEDS_BUTTON_R3   13
#define LEDS_BUTTON_A2   14
#define LEDS_BUTTON_A1   15
#define PLED_TYPE PLED_TYPE_RGB
#define PLED1_PIN 32
#define PLED2_PIN 33
#define PLED3_PIN 34
#define PLED4_PIN 35
#define PLED_COLOR ColorGreen
#define HAS_I2C_DISPLAY 1
#define I2C0_ENABLED 1
#define I2C0_PIN_SDA 4
#define I2C0_PIN_SCL 5
#define DISPLAY_I2C_BLOCK i2c0
#define REVERSE_UP_DEFAULT 1
#define REVERSE_DOWN_DEFAULT 1
#define REVERSE_LEFT_DEFAULT 1
#define REVERSE_RIGHT_DEFAULT 1
#define BUTTON_LAYOUT BUTTON_LAYOUT_BOARD_DEFINED_A
#define BUTTON_LAYOUT_RIGHT BUTTON_LAYOUT_BOARD_DEFINED_B
#define SPLASH_MODE SPLASH_MODE_STATIC
#define SPLASH_DURATION 3000
#define DEFAULT_BOARD_LAYOUT_A {\
    {GP_ELEMENT_PIN_BUTTON, {46, 53, 9, 9, 1, 1, 11, GP_SHAPE_ELLIPSE}},\
    {GP_ELEMENT_PIN_BUTTON, {22, 27, 6, 6, 1, 1, 8,  GP_SHAPE_ELLIPSE}},\
    {GP_ELEMENT_PIN_BUTTON, {36, 27, 6, 6, 1, 1, 9,  GP_SHAPE_ELLIPSE}},\
    {GP_ELEMENT_PIN_BUTTON, {46, 36, 6, 6, 1, 1, 10, GP_SHAPE_ELLIPSE}},\
    {GP_ELEMENT_PIN_BUTTON, {43, 15, 6, 6, 1, 1, 7,  GP_SHAPE_ELLIPSE}},\
    {GP_ELEMENT_PIN_BUTTON, {4,  12, 3, 3, 1, 1, 3,  GP_SHAPE_ELLIPSE}},\
    {GP_ELEMENT_PIN_BUTTON, {12, 12, 3, 3, 1, 1, 2,  GP_SHAPE_ELLIPSE}},\
    {GP_ELEMENT_PIN_BUTTON, {20, 12, 3, 3, 1, 1, 1,  GP_SHAPE_ELLIPSE}},\
    {GP_ELEMENT_PIN_BUTTON, {28, 12, 3, 3, 1, 1, 0,  GP_SHAPE_ELLIPSE}}\
  }
  #define DEFAULT_BOARD_LAYOUT_B {\
    {GP_ELEMENT_PIN_BUTTON, {63,  29, 6, 6, 1, 1, 14,  GP_SHAPE_ELLIPSE}},\
    {GP_ELEMENT_PIN_BUTTON, {77,  25, 6, 6, 1, 1, 20,  GP_SHAPE_ELLIPSE}},\
    {GP_ELEMENT_PIN_BUTTON, {91,  25, 6, 6, 1, 1, 19,  GP_SHAPE_ELLIPSE}},\
    {GP_ELEMENT_PIN_BUTTON, {105, 25, 6, 6, 1, 1, 18,  GP_SHAPE_ELLIPSE}},\
    {GP_ELEMENT_PIN_BUTTON, {61,  43, 6, 6, 1, 1, 13,  GP_SHAPE_ELLIPSE}},\
    {GP_ELEMENT_PIN_BUTTON, {75,  39, 6, 6, 1, 1, 15,  GP_SHAPE_ELLIPSE}},\
    {GP_ELEMENT_PIN_BUTTON, {90,  39, 6, 6, 1, 1, 16,  GP_SHAPE_ELLIPSE}},\
    {GP_ELEMENT_PIN_BUTTON, {105, 39, 6, 6, 1, 1, 17,  GP_SHAPE_ELLIPSE}},\
    {GP_ELEMENT_PIN_BUTTON, {67,  16, 5, 5, 1, 1, 21,  GP_SHAPE_ELLIPSE}},\
    {GP_ELEMENT_PIN_BUTTON, {84,  14, 5, 5, 1, 1, 22,  GP_SHAPE_ELLIPSE}},\
    {GP_ELEMENT_PIN_BUTTON, {71,  52, 5, 5, 1, 1, 12,  GP_SHAPE_ELLIPSE}}\
  }
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

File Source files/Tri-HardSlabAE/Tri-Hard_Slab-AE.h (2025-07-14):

/*
 * Copyright (c) 2020 Raspberry Pi (Trading) Ltd.
 *
 * SPDX-License-Identifier: BSD-3-Clause
 */

// -----------------------------------------------------
// NOTE: THIS HEADER IS ALSO INCLUDED BY ASSEMBLER SO
//       SHOULD ONLY CONSIST OF PREPROCESSOR DIRECTIVES
// -----------------------------------------------------


#ifndef _BOARDS_TRIHARDSLABAE_H
#define _BOARDS_TRIHARDSLABAE_H

// For board detection
#define TRIHARDSLABAE

//For crappy crystal
#ifndef PICO_XOSC_STARTUP_DELAY_MULTIPLIER
#define PICO_XOSC_STARTUP_DELAY_MULTIPLIER 64
#endif

// no onboard LED

// no PICO_DEFAULT_WS2812_PIN

// --- FLASH ---
#define PICO_BOOT_STAGE2_CHOOSE_W25Q080 1

#ifndef PICO_FLASH_SPI_CLKDIV
#define PICO_FLASH_SPI_CLKDIV 2
#endif

#ifndef PICO_FLASH_SIZE_BYTES
#define PICO_FLASH_SIZE_BYTES (2 * 1024 * 1024)
#endif

// Drive high to force power supply into PWM mode (lower ripple on 3V3 at light loads)
#define PICO_SMPS_MODE_PIN 23

#ifndef PICO_RP2040_B0_SUPPORTED
#define PICO_RP2040_B0_SUPPORTED 1
#endif

#endif

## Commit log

2025-07-14 Create BoardConfig.h
    BoardConfig for this board.
2025-07-14 Create Tri-Hard_Slab-AE.h
    Board setting files related to this board.

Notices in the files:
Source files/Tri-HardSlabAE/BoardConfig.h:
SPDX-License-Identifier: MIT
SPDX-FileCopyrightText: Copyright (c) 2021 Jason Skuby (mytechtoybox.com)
